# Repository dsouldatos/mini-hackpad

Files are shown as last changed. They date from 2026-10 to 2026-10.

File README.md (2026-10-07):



# Mini Keyboard 🎛️

A compact custom-designed mini keyboard featuring **4 mechanical-style switches** and a **rotary encoder**. The keyboard is designed to be small, simple, and customizable while keeping a clean modern look.

## ✨ Features

* 4 customizable switches
* 1 rotary encoder
* Custom-designed PCB
* Custom 3D-printed case
* Compact and portable design
* LED lighting
* Designed in CAD
* Easy to customize and modify


## 🛠️ BOM
* Custom PCB
*  Custom 3D-printed enclosure
* 1 Seeeduino XIAO microcontroller
* 4 MX switches
* 1 rotary encoder
* 7 SK6812 MINI-E LEDs
* 1 Soldering Iron
* Printing Legion Grant
* Hackpad PCB Grant
## 📁 Project Files

* `PCB/` – PCB design files

* `CAD/` – 3D models and enclosure

* `Firmware/` – Keyboard firmware

* `README.md` – Project information

## 🚀 Project Status

The PCB and enclosure have been designed
## 📜 License

This project is open-source. You are welcome to use, modify, and improve the design.

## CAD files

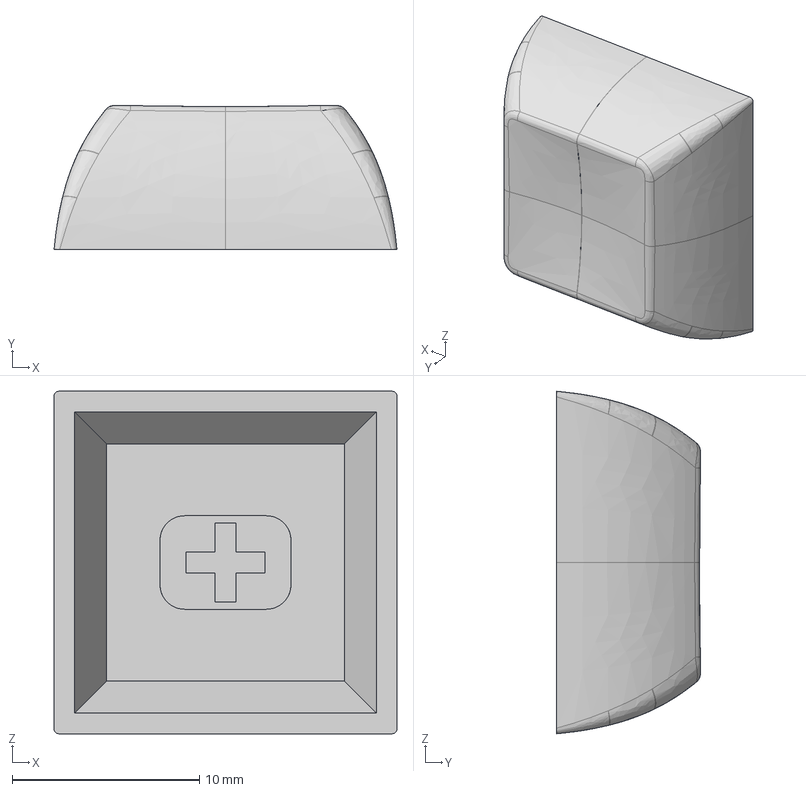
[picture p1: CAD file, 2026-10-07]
3d models/Keycap_CherryMX.step
18.3 x 7.69 x 18.3 mm

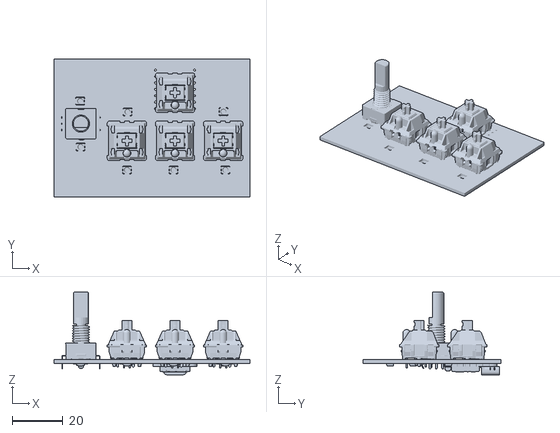
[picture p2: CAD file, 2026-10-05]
PCB desin/3D model of pcb for mini keybord.stl
77.6 x 54.6 x 32.7

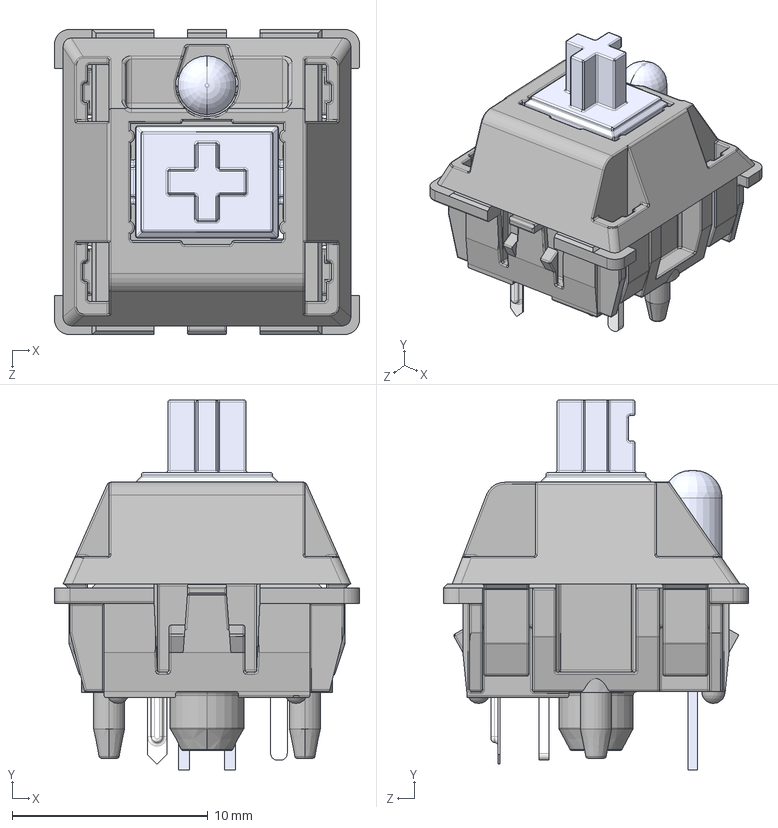
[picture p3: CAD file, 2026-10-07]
3d models/MX_Switches .STEP
15.6 x 18.9 x 15.6 mm
MX 轴 按键′_ü___¨1
MX 轴 轴体áì_¨￠¨__
MX粣 拸簽LEDLEDLED
MX轴 轴体 底部 μ×2__默认_á2____è_
针脚___默认__è_

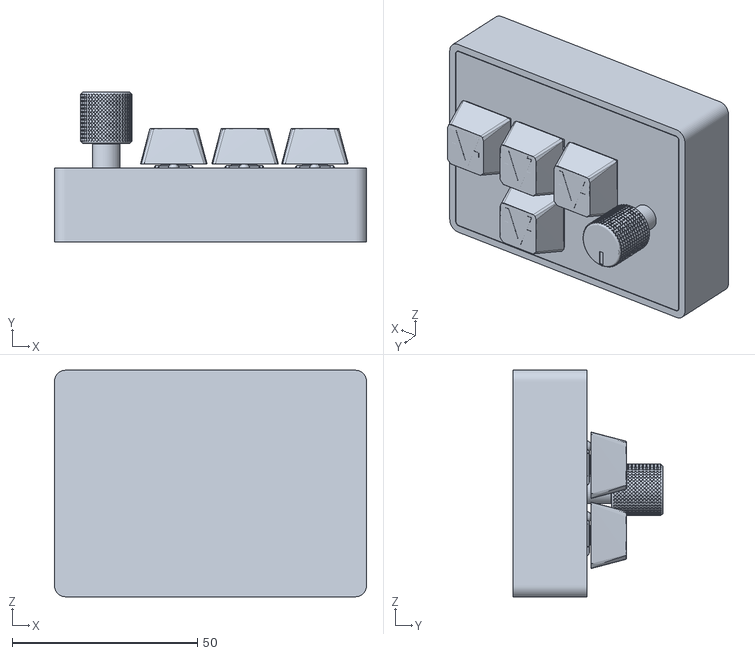
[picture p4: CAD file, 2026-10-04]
3d models/Mini keybord 1.stl
84.2 x 40.5 x 61.2

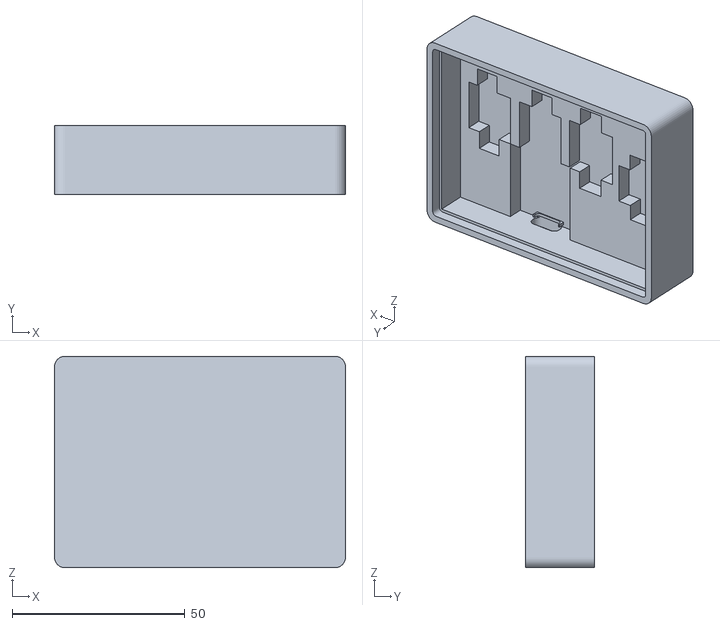
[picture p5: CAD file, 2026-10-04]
3d models/Case.stl
84.2 x 20.0 x 61.2

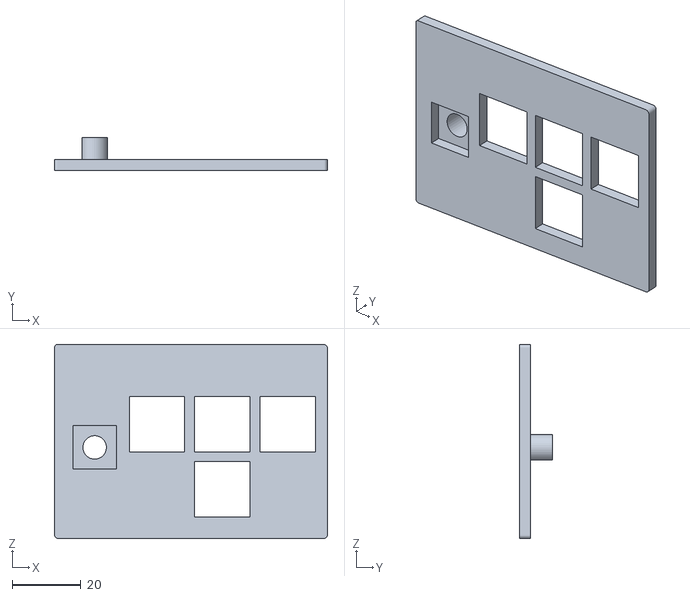
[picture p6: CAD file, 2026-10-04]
3d models/Lid.stl
79.7 x 9.70 x 56.7

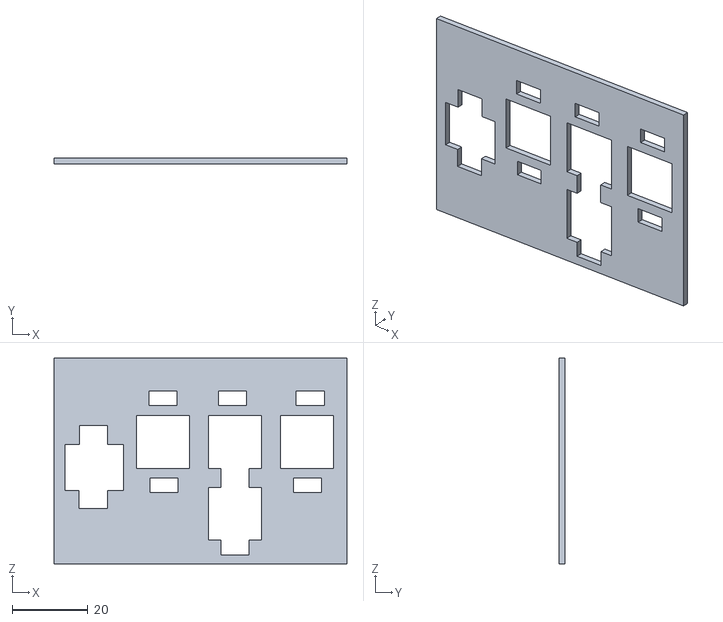
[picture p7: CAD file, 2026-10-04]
3d models/Mounting plate.stl
77.6 x 1.60 x 54.6

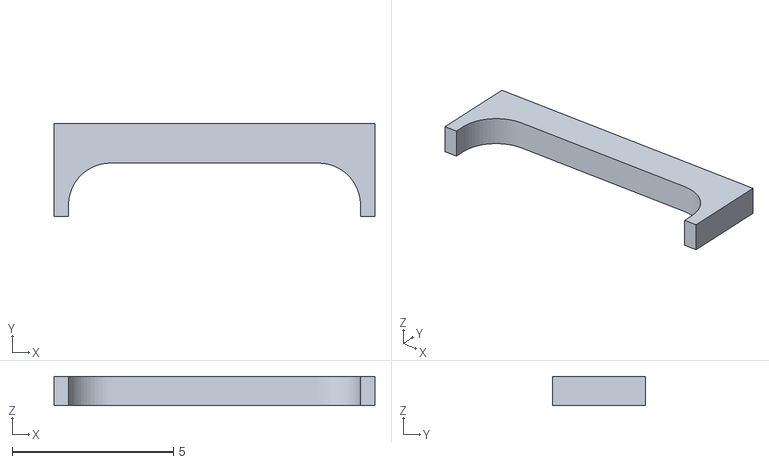
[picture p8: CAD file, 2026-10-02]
3d models/USB C Suport.stl
9.94 x 2.89 x 0.9

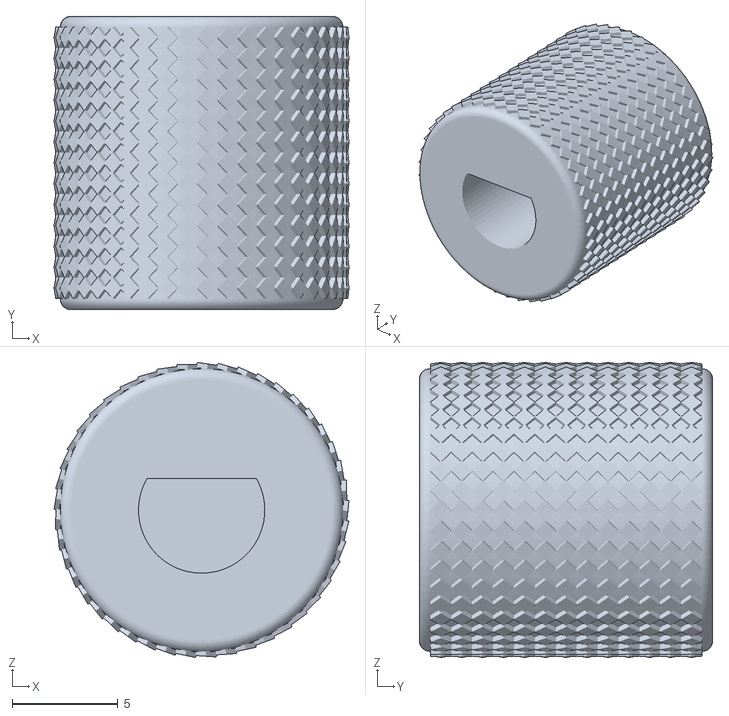
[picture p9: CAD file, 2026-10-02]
3d models/Encoder Knob.stl
14.0 x 13.9 x 14.0

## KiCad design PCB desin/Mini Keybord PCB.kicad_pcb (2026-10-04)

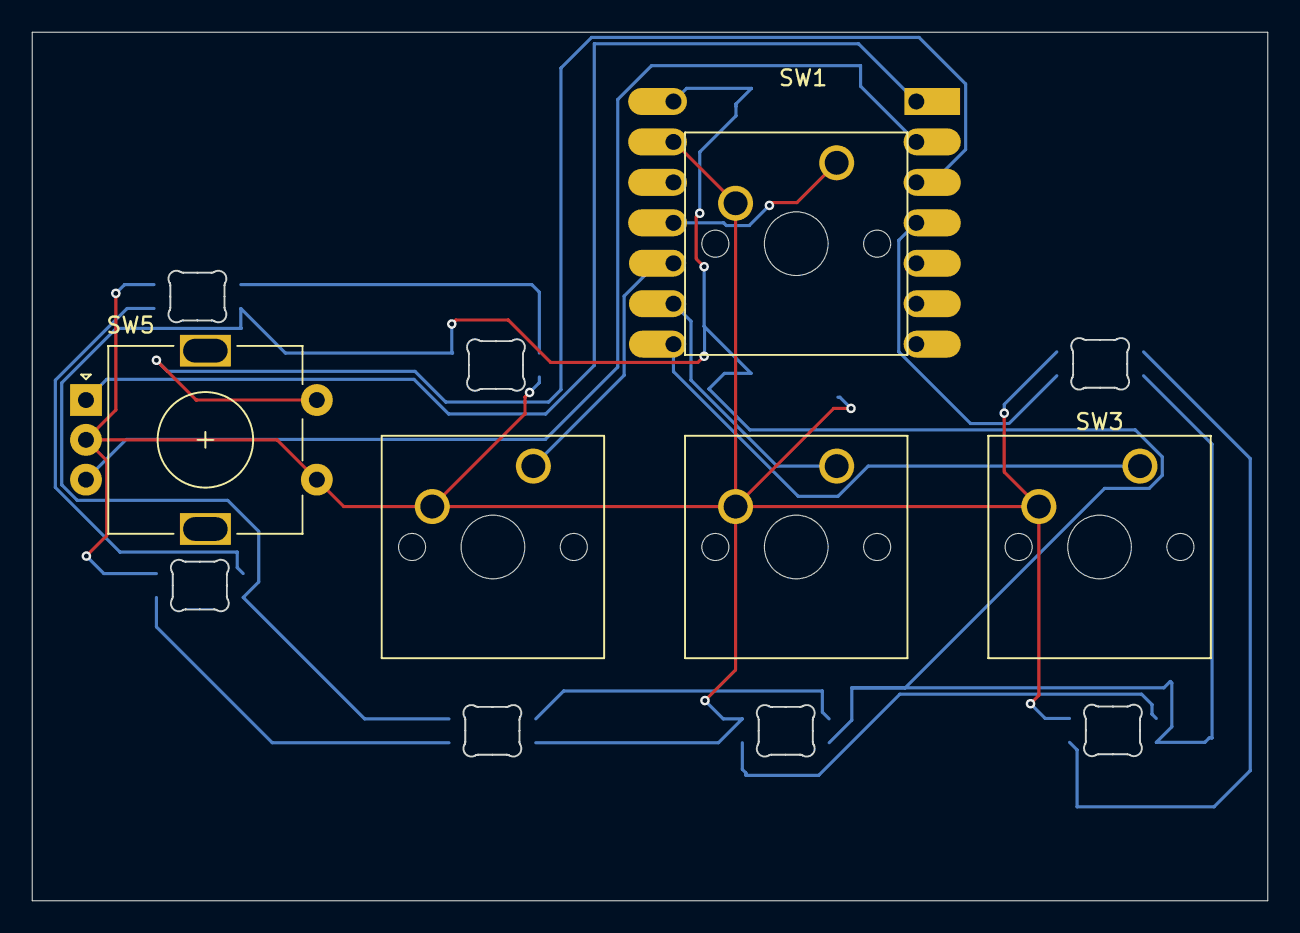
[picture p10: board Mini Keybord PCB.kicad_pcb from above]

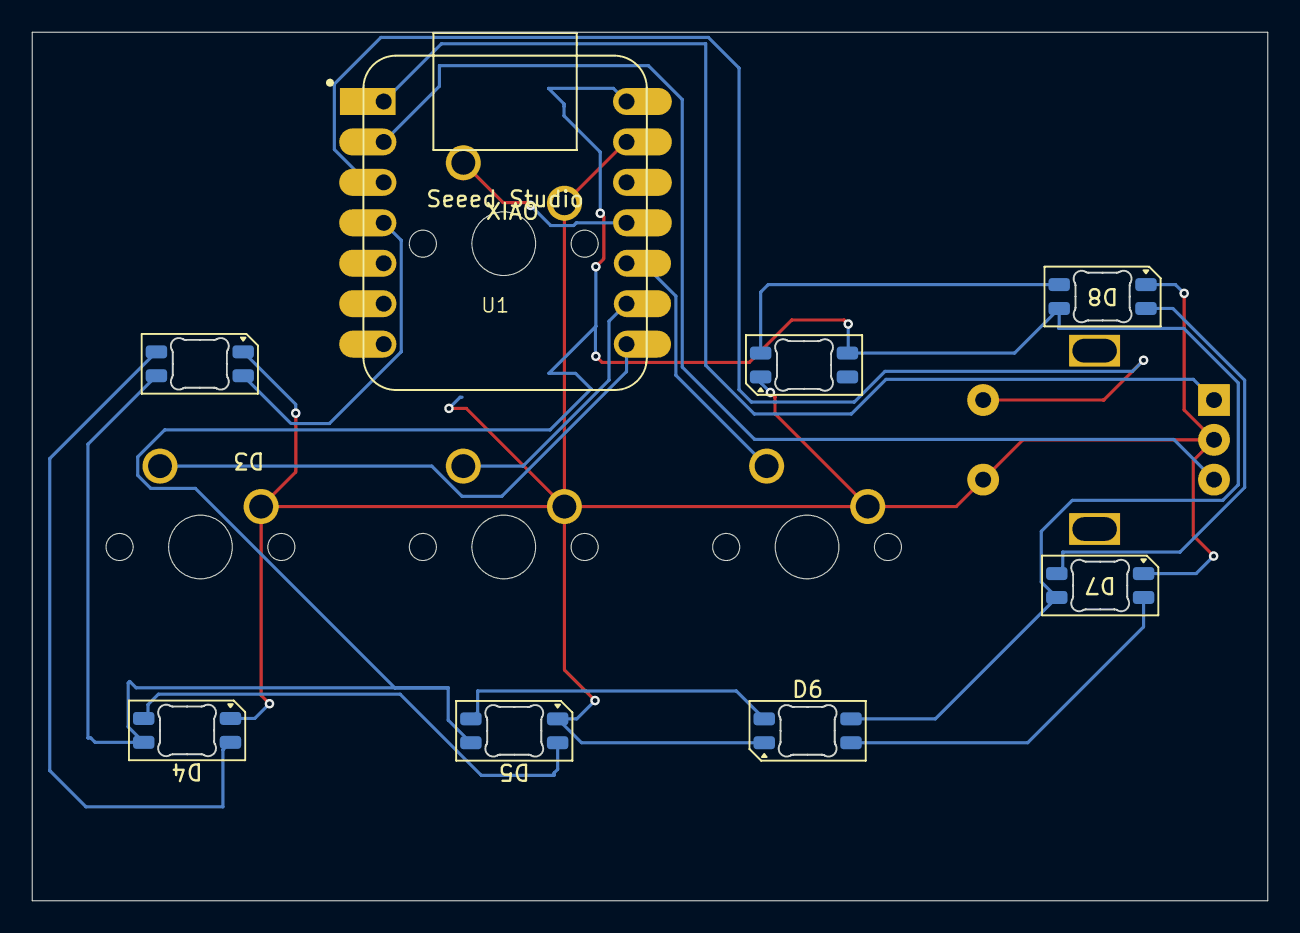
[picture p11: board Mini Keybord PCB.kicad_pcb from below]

Board: 2 copper layers, 77.6 x 54.5 mm, 13 parts (8 on the bottom side), 16 nets.

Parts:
D3, D4, D5, D6, D7, D8, D9: SK6812MINI-E; LED_SK6812MINI-E_3.2x2.8mm_P1.5mm_ReverseMount
SW1, SW2, SW3, SW4: SW_Push; SW_Cherry_MX_1.00u_PCB
SW5: RotaryEncoder_Switch; RotaryEncoder_Alps_EC11E-Switch_Vertical_H20mm
U1: MOUDLE-SEEEDUINO-XIAO; XIAO-Generic-Hybrid-14P-2.54-21X17.8MM

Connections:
GND: D3.1 (VSS), D4.1 (VSS), D5.1 (VSS), D6.1 (VSS), D7.1 (VSS), D8.1 (VSS), D9.1 (VSS), SW1.2, SW2.2, SW3.2, SW4.2, SW5.C, SW5.S1, U1.13 (GND)
unnamed: D3.2 (DIN), U1.4 (PA11_A3_D3)
unnamed: D3.4 (DOUT), D4.2 (DIN)
unnamed: D3.3 (VDD), D4.3 (VDD), D5.3 (VDD), D6.3 (VDD), D7.3 (VDD), D8.3 (VDD), D9.3 (VDD), U1.14 (5V)
unnamed: D4.4 (DOUT), D5.2 (DIN)
unnamed: D5.4 (DOUT), D6.2 (DIN)
unnamed: D6.4 (DOUT), D7.2 (DIN)
unnamed: D7.4 (DOUT), D8.2 (DIN)
unnamed: D8.4 (DOUT), D9.2 (DIN)
unnamed: SW5.A, U1.1 (PA02_A0_D0)
unnamed: SW5.B, U1.2 (PA4_A1_D1)
unnamed: SW4.1, U1.10 (PA5_A9_D9_MISO)
unnamed: SW1.1, U1.11 (PA6_A10_D10_MOSI)
unnamed: SW2.1, U1.9 (PA7_A8_D8_SCK)
unnamed: SW5.S2, U1.3 (PA10_A2_D2)
unnamed: SW3.1, U1.8 (PB09_A7_D7_RX)

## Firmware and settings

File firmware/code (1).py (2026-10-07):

"""
Mini keyboard firmware (CircuitPython)
Seeed XIAO RP2040 + 4x MX switches (arrow keys) + EC11E encoder + 7x SK6812 MINI-E

Layout (inverted T, like a real arrow cluster):
            [SW1 = UP]
  [SW2 = DOWN] [SW4 = LEFT] [SW3 = RIGHT]

Pins and LED chain order are taken from schematic
"""

import time
import board
import keypad
import rotaryio
import neopixel
import usb_hid
from adafruit_hid.keyboard import Keyboard
from adafruit_hid.keycode import Keycode
from adafruit_hid.consumer_control import ConsumerControl
from adafruit_hid.consumer_control_code import ConsumerControlCode

# ----------------------------------------------------------------------------
# PINS
# ----------------------------------------------------------------------------
LED_PIN = board.D3          # LED data (into D3's DIN)

PINS = {
    "SW1": board.D10,
    "SW2": board.D8,
    "SW3": board.D7,
    "SW4": board.D9,
    "ENC": board.D2,        # encoder push button (S2; S1 and C go to GND)
}
ENC_A_PIN = board.D0        # encoder A  (swap A and B if the volume goes backwards)
ENC_B_PIN = board.D1        # encoder B

# ----------------------------------------------------------------------------
# KEYS
# ----------------------------------------------------------------------------
KEYMAP = {
    "SW1": Keycode.UP_ARROW,
    "SW2": Keycode.DOWN_ARROW,
    "SW3": Keycode.RIGHT_ARROW,
    "SW4": Keycode.LEFT_ARROW,
}

# ----------------------------------------------------------------------------
# LEDs - numbered like on your PCB: the first LED in the chain is number 3,
# so your 7 LEDs are 3, 4, 5, 6, 7, 8, 9.
# ----------------------------------------------------------------------------
NUM_LEDS = 7
# LED number (D3..D9) of each LED in data-chain order, read from the schematic:
# DIN -> D3 -> D5 -> D4 -> D6 -> D7 -> D9 -> D8
# If a button lights the wrong LED, fix the order here.
LED_ORDER = (3, 5, 4, 6, 7, 9, 8)

WHITE = (255, 255, 255)
LED_MAP = {
    "SW1": ((3, 9), WHITE),     
    "SW2": ((5,), WHITE),
    "SW3": ((3, 4), WHITE),
    "SW4": ((9, 6), WHITE),
    "ENC": ((8, 9), WHITE),
}

ENC_STEPS_PER_DETENT = 4    # EC11: usually 2 or 4
BRIGHTNESS = 0.3
FADE = 0.88                 # closer to 1 = slower fade after release

# ----------------------------------------------------------------------------
# SETUP
# ----------------------------------------------------------------------------
NAMES = ("SW1", "SW2", "SW3", "SW4", "ENC")

kbd = Keyboard(usb_hid.devices)
cc = ConsumerControl(usb_hid.devices)

keys = keypad.Keys(tuple(PINS[n] for n in NAMES), value_when_pressed=False, pull=True)

encoder = rotaryio.IncrementalEncoder(ENC_A_PIN, ENC_B_PIN)
last_pos = encoder.position

pixels = neopixel.NeoPixel(
    LED_PIN, NUM_LEDS, brightness=BRIGHTNESS, auto_write=False, pixel_order=neopixel.GRB
)
pixels.fill((0, 0, 0))
pixels.show()

targets = {}
for name in NAMES:
    leds, color = LED_MAP[name]
    idx = [LED_ORDER.index(n) for n in leds if n in LED_ORDER]
    bad = [n for n in leds if n not in LED_ORDER]
    if bad:
        print("WARNING:", name, "uses LED", bad, "which does not exist (valid: 3-9)")
    targets[name] = (idx, color)

held = {n: False for n in NAMES}
level = [0.0] * NUM_LEDS
color_of = [WHITE] * NUM_LEDS

# ----------------------------------------------------------------------------
# MAIN LOOP
# ----------------------------------------------------------------------------
while True:
    # --- buttons ---
    while True:
        event = keys.events.get()
        if event is None:
            break
        name = NAMES[event.key_number]
        held[name] = event.pressed
        if name == "ENC":
            if event.pressed:
                cc.send(ConsumerControlCode.MUTE)
        elif event.pressed:
            kbd.press(KEYMAP[name])
        else:
            kbd.release(KEYMAP[name])

    # --- encoder rotation -> volume ---
    delta = encoder.position - last_pos
    if abs(delta) >= ENC_STEPS_PER_DETENT:
        detents = int(delta / ENC_STEPS_PER_DETENT)
        last_pos += detents * ENC_STEPS_PER_DETENT
        code = (
            ConsumerControlCode.VOLUME_INCREMENT
            if detents > 0
            else ConsumerControlCode.VOLUME_DECREMENT
        )
        for _ in range(abs(detents)):
            cc.send(code)

    # --- LEDs: full while held, then fade out ---
    for i in range(NUM_LEDS):
        level[i] *= FADE
        if level[i] < 0.02:
            level[i] = 0.0
    for name in NAMES:
        if held[name]:
            idx, color = targets[name]
            for i in idx:
                level[i] = 1.0
                color_of[i] = color
    for i in range(NUM_LEDS):
        r, g, b = color_of[i]
        pixels[i] = (int(r * level[i]), int(g * level[i]), int(b * level[i]))
    pixels.show()

    time.sleep(0.01)

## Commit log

2026-10-04 Rename 3d modeles/Mini Keybord_Configuration 1_Case.stl to 3d Case.stl
    [3d Case.stl]
2026-10-04 Rename 3d modeles/Mini Keybord_Configuration 1_USB C Suport.stl to USB C Suport.stl
    [USB C Suport.stl]
2026-10-05 Sync PCBs from Half Life
